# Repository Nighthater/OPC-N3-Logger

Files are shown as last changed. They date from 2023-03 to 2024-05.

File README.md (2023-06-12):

# OPC-N3 Aerosol Sensor Logger

This Logger records the measured data of an OPC-N3 Aerosol sensor every 5 seconds. The measured interval is 2.5sec long.  
It works fully automatic and begins recording when connected with power and needs no further oversight.

## Images

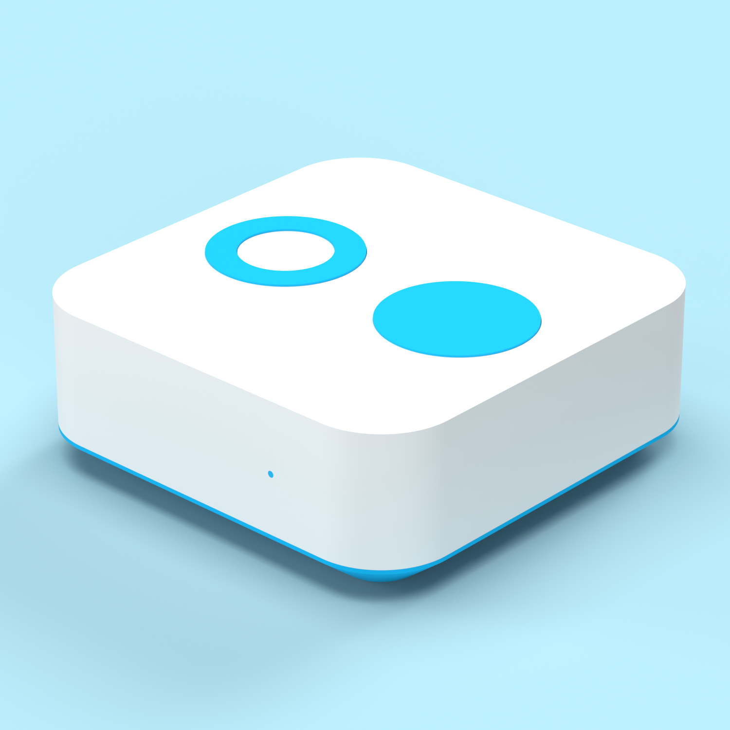
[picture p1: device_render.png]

Render of the Logger  

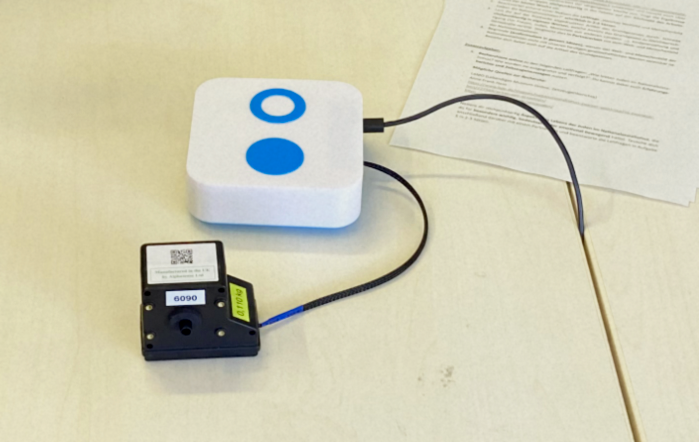
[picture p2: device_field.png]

Logger in the field  
### Size:
  LogBox M (120x120x45mm)  
  5V/300mA  
  
### Specs:
  - NodeMCU V3 LoLin MCU  
  - Real Time Clock DS3231  
  - Micro SD Card Reader  

### IO:
  - Micro USB-B for Power and Serial Data  
  - OPC-N3 Connector Cable  (6pin Molex Pico-Clasp Connector)  
  - OLED Display

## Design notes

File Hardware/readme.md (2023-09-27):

## Part List

### Electrical

- PCB
- Lolin ESP MCU
- SSD1306 OLED Display 0.96"
- MicroSD SPI Board
- DS3231 I²C Board
- Micro USB 30cm Panel Mount Extension with 2x M3 Screws ~29mm hole distance
- 2.54mm THT Screwterminals
- Molex PicoClasp 6pin Cable for the OPC

### Hardware

- 3x M4 Ruthex Threaded Inserts
- 3x Short M4 Screws
- 2x Short M3 Screws (USB Panelmount)
- Hotglue as Strain relief for the OPC Cable

## Additional info

The assembly helpers aid you in soldering the Terminals required to connect the OLED Display and the 6pin OPC Cable to the Mainboard.
You will also need 2 Smaller screws for the Micro USB.
For the Micro SD Card Reader, mount everyting in place without soldering it on.
Solder the Connection to the Mainboard, when the Reader is inserted into the Case, same with the OLED display.

You will have to cut the pico clasp cable, strip the thin cable carefully (I used a Knipex 12 40 200 wire Stripper), and connect it to the terminals.
Use solder on the wire to make it mechanically stronger.
You will need a multimeter to figue out what connection belongs to the cable strand.
I also found it helpful to use braid sleeving to protect the thin cable.

## Schematics

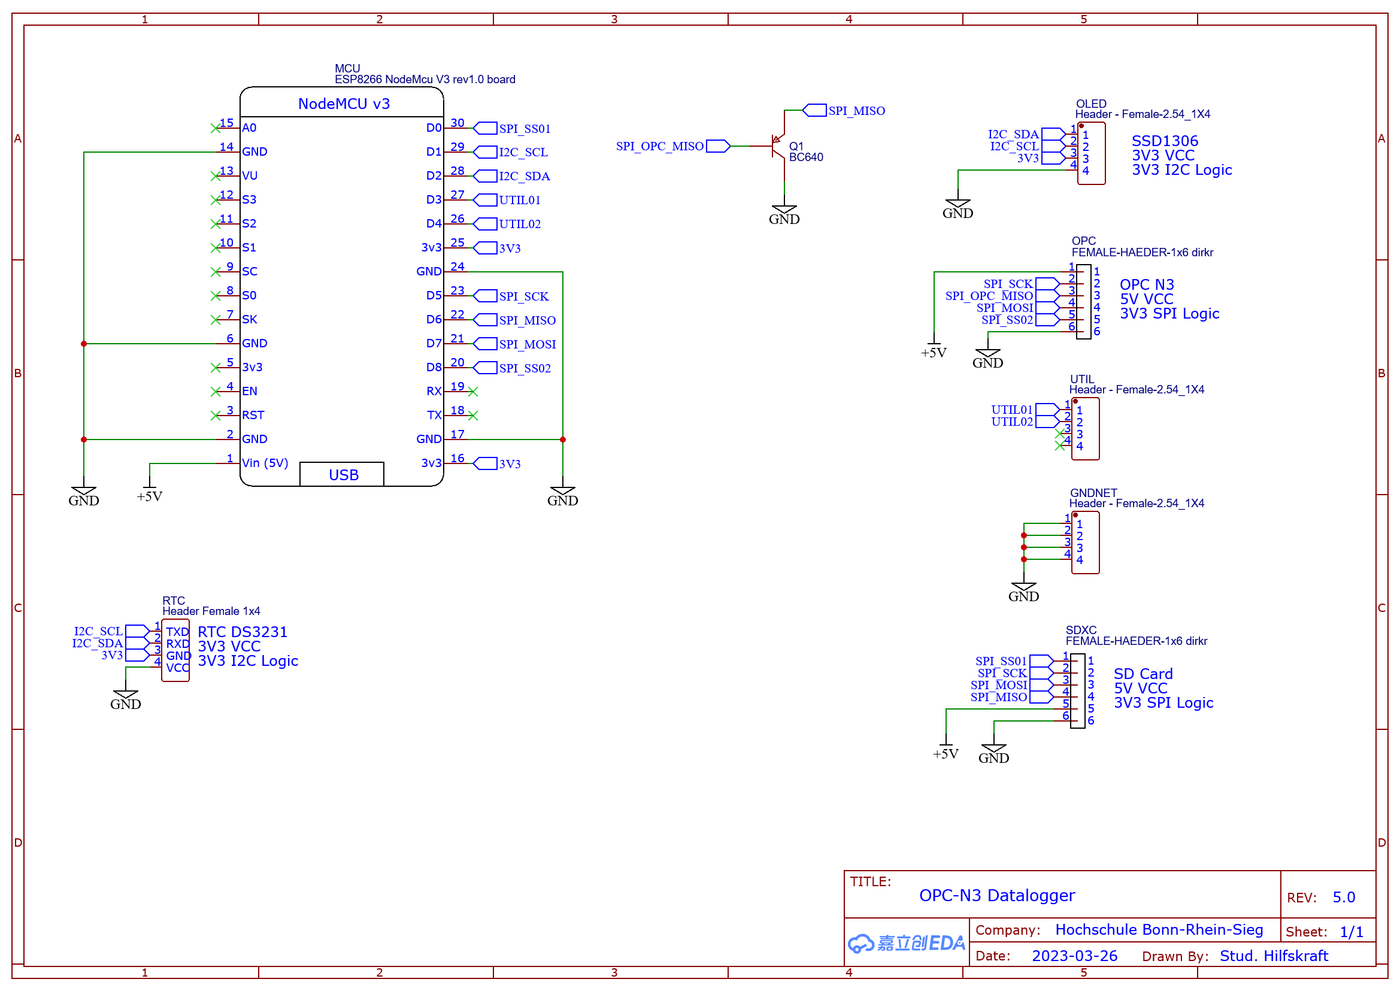
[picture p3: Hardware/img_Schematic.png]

Electrical Schematic  

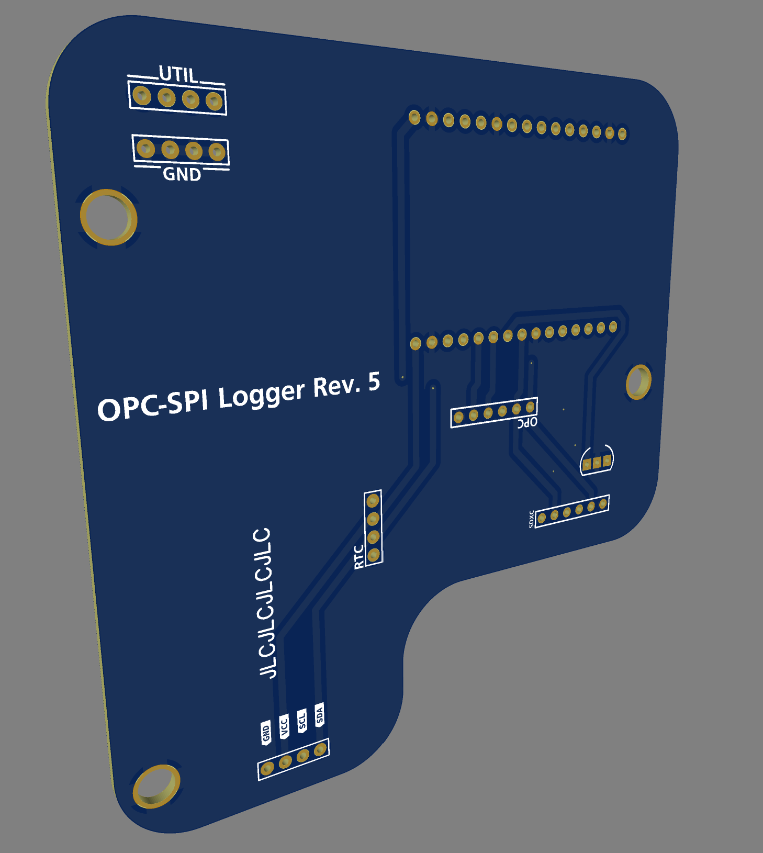
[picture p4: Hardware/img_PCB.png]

Printed Circuit Board screenshot

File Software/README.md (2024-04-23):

The Software comes in two versions.  
One with support for a RTC and one without.

With an RTC, the Filename contains the Date when the File was created.  

Without an RTC the Filename simply increments everytime a File is created, starting always from 0.
If you want to continue from an index, include an empty csv with the Format <DeviceID>_<Index>.csv.

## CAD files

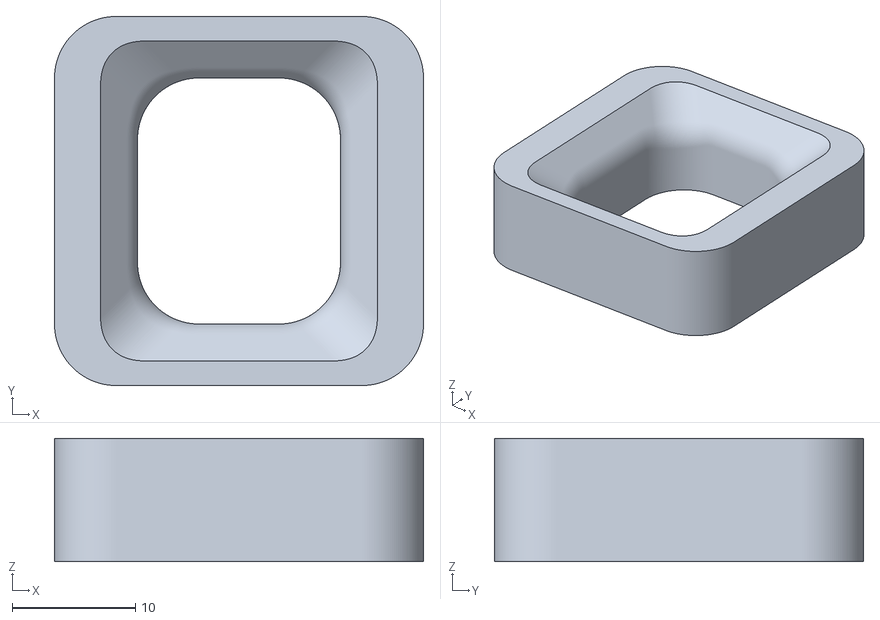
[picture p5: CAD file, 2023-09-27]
Hardware/STL/AssemblyHelper_3xTerminals.stl
30.0 x 30.0 x 10.0

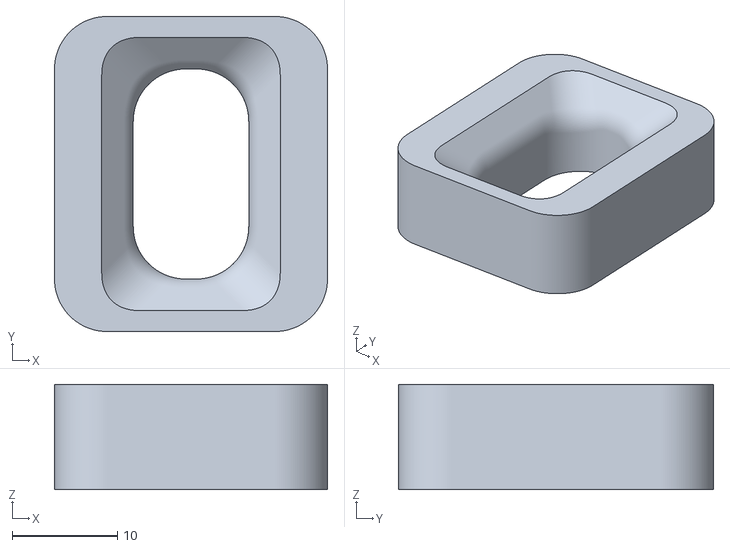
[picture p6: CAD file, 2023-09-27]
Hardware/STL/AssemblyHelper_2xTerminals.stl
26.0 x 30.0 x 10.0

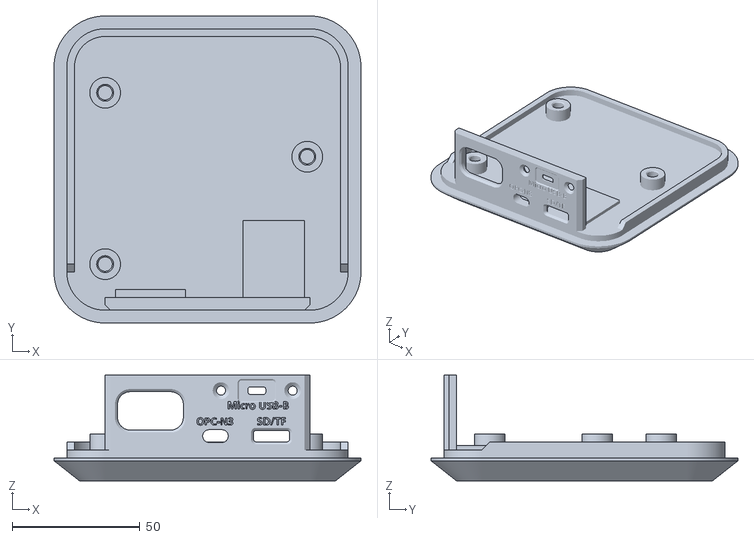
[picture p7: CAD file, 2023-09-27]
Hardware/STL/Casing_Shell_Bottom.stl
120.0 x 120.0 x 41.4

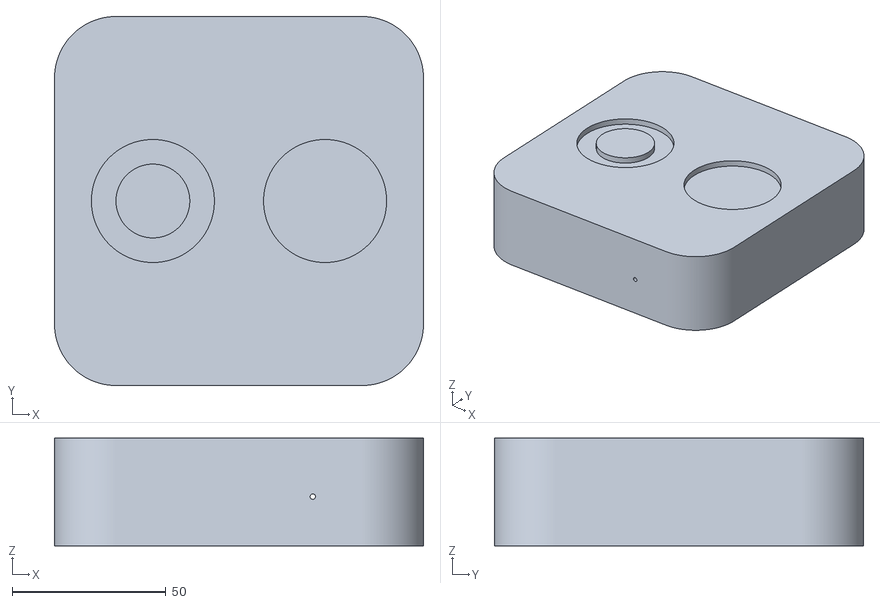
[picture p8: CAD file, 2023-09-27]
Hardware/STL/Casing_Shell_Outer.stl
120.0 x 120.0 x 35.0

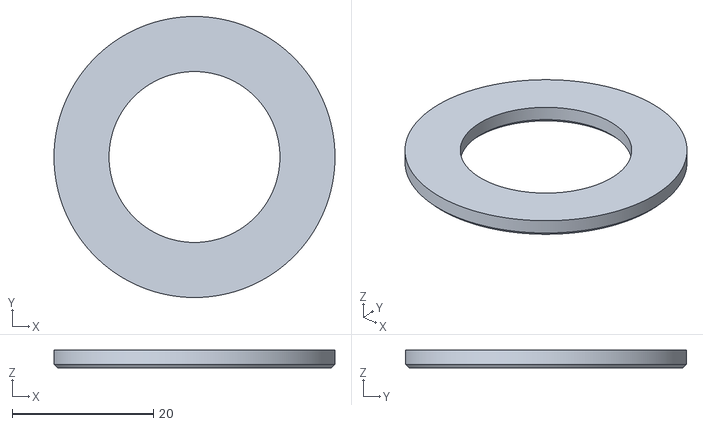
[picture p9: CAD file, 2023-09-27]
Hardware/STL/Casing Logo_Ring.stl
39.8 x 39.8 x 2.50

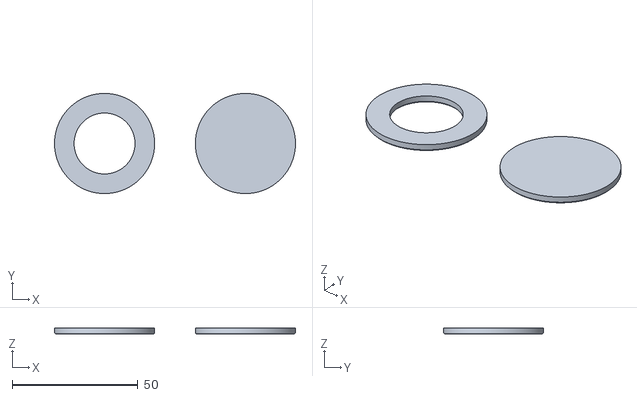
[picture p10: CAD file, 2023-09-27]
Hardware/STL/Casing Logo.stl
95.8 x 39.8 x 2.50

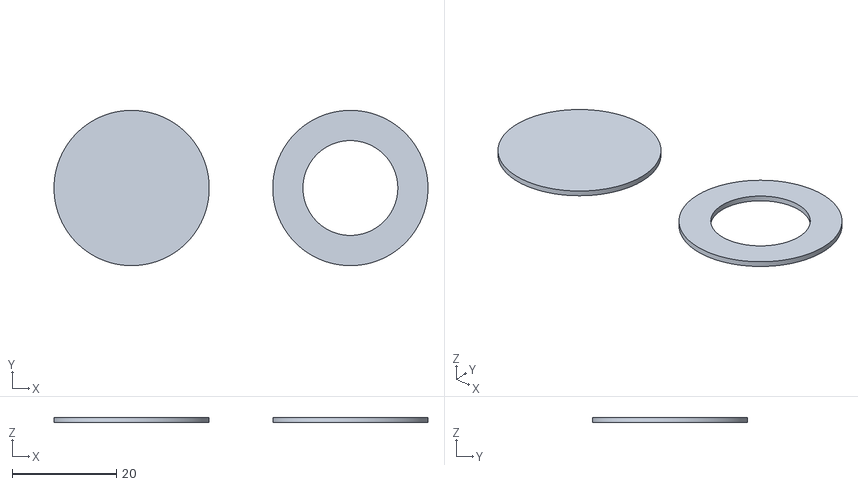
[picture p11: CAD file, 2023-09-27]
Hardware/STL/Casing_Logo_Bottom.stl
71.8 x 29.8 x 1.00

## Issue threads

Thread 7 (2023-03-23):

Screwholes don't fit

Nighthater, 2023-03-23:
The Case is designed for M4 screws, however the PCB has a hole diameter of 3.5mm (M3)

Nighthater, 2023-03-25:
Screwholes have been made fitting in Revision 5

Nighthater, 2023-03-26:
Closed by #11

Closed 2023-03-26.

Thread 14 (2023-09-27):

OPC-N3 Power Requirements

yash-dahima, 2023-09-27:
Hi @Nighthater,

Thanks for this work. I do not have much experience in electronics, so I am facing some trouble in providing proper power to the OPC-N3. Please suggest me how should I power it when using it with along either ESP32 or Raspberry Pi?

Should I power it via RPi/ESP or should I power it separately via 5V mobile charging adapter? I tried to power it via ESP32 Vin and GND pins, but its not working. Your help would be greatly appreciated. Thanks :)

Nighthater, 2023-09-27:
Hi @yash-dahima,

You can power the OPC with either the VIN/GND pins (RPi: 5V/GND) or a 5V Charging adapter. When using an external power supply, like an external charger, make sure that the GND of the Charger and the GND of the ESP/RPi are connected together.

The sensor also won't power on after supplying it with power. You have to send it commands to start up and start measuring data.

Do you currently use an ESP or a RPi to interface with the OPC?
You should also consider that the SPI logic levels on the OPC-N3 Sensor are 3.3V, despite its 5V power supply. I chose an ESP because of that. A RPi uses 5V logic and probably wont recognize a 3.3V high Signal.

yash-dahima, 2023-09-27:
Thanks you very much @Nighthater for your prompt response. I will attempt as per your suggestions and will let you know how it goes.
Again thanks and best wishes :)

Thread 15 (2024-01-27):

RTC sometimes reverts back to 2000-01-01

Nighthater, 2024-01-27:
After setting the time, the RTC will revert to factory settings after a few minutes without power.
Either Hardware or Software fault.

Closed 2024-04-23.

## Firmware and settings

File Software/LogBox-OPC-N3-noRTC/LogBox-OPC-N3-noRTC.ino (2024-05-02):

/*
██╗░░░░░░█████╗░░██████╗░██████╗░░█████╗░██╗░░██╗  ░█████╗░██████╗░░█████╗░░░░░░░███╗░░██╗██████╗░
██║░░░░░██╔══██╗██╔════╝░██╔══██╗██╔══██╗╚██╗██╔╝  ██╔══██╗██╔══██╗██╔══██╗░░░░░░████╗░██║╚════██╗
██║░░░░░██║░░██║██║░░██╗░██████╦╝██║░░██║░╚███╔╝░  ██║░░██║██████╔╝██║░░╚═╝█████╗██╔██╗██║░█████╔╝
██║░░░░░██║░░██║██║░░╚██╗██╔══██╗██║░░██║░██╔██╗░  ██║░░██║██╔═══╝░██║░░██╗╚════╝██║╚████║░╚═══██╗
███████╗╚█████╔╝╚██████╔╝██████╦╝╚█████╔╝██╔╝╚██╗  ╚█████╔╝██║░░░░░╚█████╔╝░░░░░░██║░╚███║██████╔╝
╚══════╝░╚════╝░░╚═════╝░╚═════╝░░╚════╝░╚═╝░░╚═╝  ░╚════╝░╚═╝░░░░░░╚════╝░░░░░░░╚═╝░░╚══╝╚═════╝░


MIT License

Copyright (c) 2024 NIGHTHATER

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
THE SOFTWARE IS PROVIDED "AS IS", WITHOUT WARRANTY OF ANY KIND, EXPRESS OR
IMPLIED, INCLUDING BUT NOT LIMITED TO THE WARRANTIES OF MERCHANTABILITY,
FITNESS FOR A PARTICULAR PURPOSE AND NONINFRINGEMENT. IN NO EVENT SHALL THE
AUTHORS OR COPYRIGHT HOLDERS BE LIABLE FOR ANY CLAIM, DAMAGES OR OTHER
LIABILITY, WHETHER IN AN ACTION OF CONTRACT, TORT OR OTHERWISE, ARISING FROM,
OUT OF OR IN CONNECTION WITH THE SOFTWARE OR THE USE OR OTHER DEALINGS IN THE
SOFTWARE.
*/


//█▄▄ ▄▀█ █▀ █ █▀▀   █░░ █ █▄▄ █▀█ ▄▀█ █▀█ █ █▀▀ █▀
//█▄█ █▀█ ▄█ █ █▄▄   █▄▄ █ █▄█ █▀▄ █▀█ █▀▄ █ ██▄ ▄█


#include "math.h"
#include <Wire.h>
#include <SPI.h>

// OLED DISPLAY SSD1306 | by Adafruit
// https://www.arduino.cc/reference/en/libraries/adafruit-ssd1306/
#include <Adafruit_SSD1306.h>
#include <Adafruit_GFX.h>
#include <splash.h>

// OPC-N3 Aerosol Sensor | by marlon360
// https://github.com/marlon360/opcn3-arduino
#include <OPCN3.h>

// SD Card SPI Reader | by Arduino
// https://www.arduino.cc/reference/en/libraries/sd/
#include <SD.h>


//█▀▄ █▀▀ █▀▀ █░░ ▄▀█ █▀█ ▄▀█ ▀█▀ █ █▀█ █▄░█ █▀
//█▄▀ ██▄ █▄▄ █▄▄ █▀█ █▀▄ █▀█ ░█░ █ █▄█ █░▀█ ▄█

//Pins
//Empty | Reserverd for UTIL Pins

//OLED
#define SCREEN_WIDTH 128 // OLED display width, in pixels
#define SCREEN_HEIGHT 64 // OLED display height, in pixels
#define OLED_RESET    -1 // Reset pin # (or -1 if sharing Arduino reset pin)
#define SCREEN_ADDRESS 0x3C
Adafruit_SSD1306 display(SCREEN_WIDTH, SCREEN_HEIGHT, &Wire, OLED_RESET);

//OPC-N3
OPCN3 myOPCN3(15); // SS PIN in constructor

//SD Card Reader
const int CSpin = 16; //CS PIN SD CARD
File sensorData;


//█░█ ▄▀█ █▀█ █ ▄▀█ █▄▄ █░░ █▀▀ █▀
//▀▄▀ █▀█ █▀▄ █ █▀█ █▄█ █▄▄ ██▄ ▄█

//Measurements
float VAR_Temperature = 0.0;
float VAR_Humidity = 0.0;
float VAR_Humidity_ABS = 0.0;
float VAR_PM_10 = 0.0;
float VAR_PM_2_5 = 0.0;
float VAR_PM_1 = 0.0;

uint16_t VAR_BINS[24];

//File name
String IDevice = "G02"; // Change for Device Name //------------------------------------------------------------------------------------------------------- CUSTOMIZED
String FileName = "";
int FileIndex = 0;

bool FLAG_new_file = false;

//Measurement index count
int VAR_Index = 0;

//Timer and Timing variables
unsigned long TIME_last_SD_save;
unsigned long TIME_last_display_update;
unsigned long TIME_last_RTC_update;
unsigned long TIME_last_OPC_readout;
unsigned long TIME_measurement_start;

//Timer Intervals in ms
int INTERVAL_SD_Save 		= 	5000; 			// Determines the Interval in which measurements are taken / 	in miliseconds 5000ms recommended
int INTERVAL_Display_Update 	= 	200;			// Determines the Interval in which Display is updated / 	in miliseconds 200ms recommended
int INTERVAL_OPC_Readout 	= 	2500;			// Determines the Interval in which OPC is updated / 		in miliseconds 2500ms recommended

//------------------------------------------//
//░██████╗███████╗████████╗██╗░░░██╗██████╗░//
//██╔════╝██╔════╝╚══██╔══╝██║░░░██║██╔══██╗//
//╚█████╗░█████╗░░░░░██║░░░██║░░░██║██████╔╝//
//░╚═══██╗██╔══╝░░░░░██║░░░██║░░░██║██╔═══╝░//
//██████╔╝███████╗░░░██║░░░╚██████╔╝██║░░░░░//
//╚═════╝░╚══════╝░░░╚═╝░░░░╚═════╝░╚═╝░░░░░//
//------------------------------------------//

void setup() {
	// Begin of Script
	// Errorcodes
	// 0x1x SD Card
	// 0x2x Display
	// 0x3x
	// 0x4x
	
	// Begin Serial Comms
	Serial.begin(115200);
	delay(random(50,150));
	
	//initialize OLED Display
	// SSD1306_SWITCHCAPVCC = generate display voltage from 3.3V internally
	if(!display.begin(SSD1306_SWITCHCAPVCC, SCREEN_ADDRESS)) {
		Serial.println(F("FATAL ERROR 0x2B - SSD1306 allocation failed"));
		for(;;); // Don't proceed, loop forever
	}

	display.clearDisplay();
	display.display();

	//Serial
	
	
	//Only the logo
	OLED_ASYNC_display_Startup_Logo();
	delay(random(1000,2000));
	
	//Initialize the Status bar
	OLED_ASYNC_display_Startup_Bar();
	delay(random(1500,2500));
	
	OLED_ASYNC_display_Startup_Bar_Fill(random(2,8));
	delay(random(50,300));

	Serial.print(F("compiled: "));
	Serial.print(__DATE__);
	Serial.println(__TIME__);

	
	OLED_ASYNC_display_Startup_Bar_Fill(random(13,20));
	delay(random(250,750));
	
	//Initialize SD CARD
	pinMode(CSpin, OUTPUT);
	if (!SD.begin(CSpin)) {
		Serial.println(F("FATAL ERROR 0x1A - SD-Card failed, or not present"));
		// don't do anything more:
		for(;;);
	}
	Serial.println(F("SD Card initialized."));

	OLED_ASYNC_display_Startup_Bar_Fill(random(25,35));
	delay(random(250,750));

	//initialize OPC-N3
	// turn on laser, fan and set high gain, use delay to make sure it is setup proper.
	delay(50);
	myOPCN3.initialize();
	delay(500);

	OLED_ASYNC_display_Startup_Bar_Fill(random(45,65));
	delay(random(500,1000));

	
	// Read all filenames
	const char* directory = "/"; // Directory where files are stored
	File dir = SD.open(directory);
	int maxIndex = 0;
	// find the one with the highest File index
	
	while (true) {
    File entry = dir.openNextFile();
		if (!entry) 
		{
			// No more files
			break;
		}
		String filename = entry.name();
		entry.close();

		// Parse the filename to extract the index part
		int underscoreIndex = filename.lastIndexOf('_');
		int dotIndex = filename.lastIndexOf('.');
		
		if (underscoreIndex != -1 && dotIndex != -1) 
		{
		  String indexString = filename.substring(underscoreIndex + 1, dotIndex);
		  int index = indexString.toInt();
		  if (index > maxIndex) 
		  {
			maxIndex = index;
		  }
		}
	}
	dir.close();

	FileIndex = maxIndex + 1;
	
	//Create Filename
	FileName = IDevice + '_' + FileIndex + ".csv";

	sensorData = SD.open(FileName, FILE_WRITE);
	sensorData.close();  //Closing the file

	Serial.println(FileName);

	OLED_ASYNC_display_Startup_Bar_Fill(random(70,80));
	delay(random(1000,1500));

	sensorData = SD.open(FileName, FILE_WRITE);
	if (sensorData) {
		//Write csv header
		sensorData.println("TIME;INDEX;TEMPERATURE;HUM-REL;HUM-ABS;PM10;PM2.5;PM1;BIN0;BIN1;BIN2;BIN3;BIN4;BIN5;BIN6;BIN7;BIN8;BIN9;BIN10;BIN11;BIN12;BIN13;BIN14;BIN15;BIN16;BIN17;BIN18;BIN19;BIN20;BIN21;BIN22;BIN23");
		// close the file:
		sensorData.close();
		Serial.print(F("New File Created: "));
		Serial.println(FileName);
	} else {
		Serial.println(F("FATAL ERROR 0x1B - Cannot write to new File"));
		for(;;);
	}

	OLED_ASYNC_display_Startup_Bar_Fill(100);
	delay(random(1000,1500));

	display.clearDisplay();
	display.display();
	delay(random(150,450));

	//get the measurement since the start
	TIME_measurement_start = millis();

	//set the timing variables to relative zero for the main loop
	TIME_last_SD_save = millis();
	TIME_last_display_update = millis();
	TIME_last_RTC_update = millis();
	TIME_last_OPC_readout = millis();


  SPI.setClockDivider(SPI_CLOCK_DIV32);
	Serial.println(F("Timers set, Setup complete"));

}


//--------------------------------//
//██╗░░░░░░█████╗░░█████╗░██████╗░//
//██║░░░░░██╔══██╗██╔══██╗██╔══██╗//
//██║░░░░░██║░░██║██║░░██║██████╔╝//
//██║░░░░░██║░░██║██║░░██║██╔═══╝░//
//███████╗╚█████╔╝╚█████╔╝██║░░░░░//
//╚══════╝░╚════╝░░╚════╝░╚═╝░░░░░//
//--------------------------------//


void loop() {
	//All Values, Inputs and Outputs will be updated asyncronous

	//Check for Display Update
	if(millis() - TIME_last_display_update > INTERVAL_Display_Update)
	{
		//UPDATE DISPLAY
		TIME_last_display_update = millis() - (millis() - TIME_last_display_update - INTERVAL_Display_Update);

		//Upper Part
		OLED_ASYNC_display_divider();
    OLED_ASYNC_display_Elapsed_Time();
		OLED_ASYNC_display_HBRS_Logo_top_right();

		//Lower Part
		OLED_ASYNC_display_Identifier(IDevice);
		OLED_ASYNC_display_vertical_divider();

		OLED_ASYNC_display_Elapsed_Time();
		OLED_ASYNC_display_HUM_and_TMP(VAR_Temperature,int(VAR_Humidity));
		OLED_ASYNC_display_PM_values(VAR_PM_10,VAR_PM_2_5,VAR_PM_1);
    OLED_ASYNC_display_file_name(FileName);
	}

	//Check for OPC Readout
	if(millis() - TIME_last_OPC_readout > INTERVAL_OPC_Readout)
	{
		//UPDATE OPC
		TIME_last_OPC_readout = millis() - (millis() - TIME_last_OPC_readout - INTERVAL_OPC_Readout);
		OLED_ASYNC_display_OPC_update_icon(15,3);
		
		//OPC readout:
		SPI.setClockDivider(SPI_CLOCK_DIV32);
		SPI.setDataMode(SPI_MODE1);
		HistogramData hist = myOPCN3.readHistogramData();
		
		VAR_Temperature = hist.getTempC();
    VAR_Humidity = hist.getHumidity();
    VAR_Humidity_ABS = CALC_abs_humidity(VAR_Temperature, VAR_Humidity);
		
		VAR_PM_10 = hist.pm10;
		VAR_PM_2_5 = hist.pm2_5;
		VAR_PM_1 = hist.pm1;

    VAR_BINS[0] = hist.binCount0;
    VAR_BINS[1] = hist.binCount1;
    VAR_BINS[2] = hist.binCount2;
    VAR_BINS[3] = hist.binCount3;
    VAR_BINS[4] = hist.binCount4;
    VAR_BINS[5] = hist.binCount5;
    VAR_BINS[6] = hist.binCount6;
    VAR_BINS[7] = hist.binCount7;
    VAR_BINS[8] = hist.binCount8;
    VAR_BINS[9] = hist.binCount9;
    VAR_BINS[10] = hist.binCount10;
    VAR_BINS[11] = hist.binCount11;
    VAR_BINS[12] = hist.binCount12;
    VAR_BINS[13] = hist.binCount13;
    VAR_BINS[14] = hist.binCount14;
    VAR_BINS[15] = hist.binCount15;
    VAR_BINS[16] = hist.binCount16;
    VAR_BINS[17] = hist.binCount17;
    VAR_BINS[18] = hist.binCount18;
    VAR_BINS[19] = hist.binCount19;
    VAR_BINS[20] = hist.binCount20;
    VAR_BINS[21] = hist.binCount21;
    VAR_BINS[22] = hist.binCount22;
    VAR_BINS[23] = hist.binCount23;
		
		delay(100);
		OLED_ASYNC_remove_OPC_update_icon(15,3);

	}

	//Check for SD Card save
	if(millis() - TIME_last_SD_save > INTERVAL_SD_Save)
	{
		SPI.setDataMode(SPI_MODE0);
		//UPDATE SD card
		TIME_last_SD_save = millis() - (millis() - TIME_last_SD_save - INTERVAL_SD_Save);

		OLED_ASYNC_display_save_icon(3,3);
		saveData(sensorData, FileName, VAR_Index, VAR_Temperature, VAR_Humidity, VAR_Humidity_ABS, VAR_PM_10, VAR_PM_2_5, VAR_PM_1, VAR_BINS);
		VAR_Index = VAR_Index + 1;
		
		if( (VAR_Index % 17280 == 0) && (VAR_Index != 0) ) //Since VAR_Index is a int it can only reach up to ~32k until it flips into the negative
		{
			//Schedule creation of new File every 17280 entries (24 h)
			FLAG_new_file = true;
		}
		delay(100);
		OLED_ASYNC_remove_save_icon(3,3);
	}
	
	if(FLAG_new_file == true)
	{
		FLAG_new_file = false;
		
		//Create new File
		//Prepare the Filename
		
		FileIndex = FileIndex + 1;
		
		FileName = IDevice + "_" + FileIndex + ".csv";
		
		sensorData = SD.open(FileName, FILE_WRITE);
		sensorData.close();  //Closing the file

		sensorData = SD.open(FileName, FILE_WRITE);
		if (sensorData) {
			//Write csv header
			sensorData.println("TIME;INDEX;TEMPERATURE;HUM-REL;HUM-ABS;PM10;PM2.5;PM1;BIN0;BIN1;BIN2;BIN3;BIN4;BIN5;BIN6;BIN7;BIN8;BIN9;BIN10;BIN11;BIN12;BIN13;BIN14;BIN15;BIN16;BIN17;BIN18;BIN19;BIN20;BIN21;BIN22;BIN23");
			// close the file:
			sensorData.close();
			Serial.print(F("New File Created: "));
			Serial.println(FileName);
		} else {
			Serial.println(F("FATAL ERROR 0x1B - Cannot write to new File"));
			for(;;);
		}
	}

}



//---------------------------------------------------------------------------------------//
//░██████╗██╗░░░██╗██████╗░██████╗░░█████╗░██╗░░░██╗████████╗██╗███╗░░██╗███████╗░██████╗//
//██╔════╝██║░░░██║██╔══██╗██╔══██╗██╔══██╗██║░░░██║╚══██╔══╝██║████╗░██║██╔════╝██╔════╝//
//╚█████╗░██║░░░██║██████╦╝██████╔╝██║░░██║██║░░░██║░░░██║░░░██║██╔██╗██║█████╗░░╚█████╗░//
//░╚═══██╗██║░░░██║██╔══██╗██╔══██╗██║░░██║██║░░░██║░░░██║░░░██║██║╚████║██╔══╝░░░╚═══██╗//
//██████╔╝╚██████╔╝██████╦╝██║░░██║╚█████╔╝╚██████╔╝░░░██║░░░██║██║░╚███║███████╗██████╔╝//
//╚═════╝░░╚═════╝░╚═════╝░╚═╝░░╚═╝░╚════╝░░╚═════╝░░░░╚═╝░░░╚═╝╚═╝░░╚══╝╚══════╝╚═════╝░//
//---------------------------------------------------------------------------------------//


//█▀ █▀▄   █▀▀ ▄▀█ █▀█ █▀▄   █▀ ▄▀█ █░█ █ █▄░█ █▀▀
//▄█ █▄▀   █▄▄ █▀█ █▀▄ █▄▀   ▄█ █▀█ ▀▄▀ █ █░▀█ █▄█

void saveData(File sensorData, String FileName, int VAR_Index, float VAR_Temperature, float VAR_Humidity, float VAR_Humidity_ABS ,float VAR_PM_10, float VAR_PM_2_5, float VAR_PM_1, uint16_t VAR_BINS[24]){
	if(SD.exists(FileName)) // check the file is still there
	//sensorData.println("DATE;TIME;INDEX;TEMPERATURE;HUM-REL;HUM-ABS;PM10;PM2.5;PM1;BIN0;BIN1;BIN2;BIN3;BIN4;BIN5;BIN6;BIN7;BIN8;BIN9;BIN10;BIN11;BIN12;BIN13;BIN14;BIN15;BIN16;BIN17;BIN18;BIN19;BIN20;BIN21;BIN22;BIN23");
	{ 
		// now append new data file
		sensorData = SD.open(FileName, FILE_WRITE);
		if (sensorData)
		{
			//Write to SD Card
			unsigned long currentMillis = millis();
      unsigned long seconds = currentMillis / 1000;
      unsigned long minutes = seconds / 60;
      unsigned long hours = minutes / 60;
      unsigned long days = hours / 24;
      currentMillis %= 1000;
      seconds %= 60;
      minutes %= 60;
      hours %= 24;
			sensorData.print(hours);
			sensorData.print(':');
			sensorData.print(minutes);
			sensorData.print(':');
			sensorData.print(seconds);
			sensorData.print(';');
			sensorData.print(VAR_Index);
			sensorData.print(';');
			sensorData.print(VAR_Temperature,1); // Maybe replace . with ,
			sensorData.print(';');
			sensorData.print(float(VAR_Humidity),0); // Maybe replace . with ,
			sensorData.print(';');
      sensorData.print(VAR_Humidity_ABS);
      sensorData.print(';');
			sensorData.print(VAR_PM_10,3); // Maybe replace . with ,
			sensorData.print(';');
			sensorData.print(VAR_PM_2_5,3); // Maybe replace . with ,
			sensorData.print(';');
			sensorData.print(VAR_PM_1,3); // Maybe replace . with ,
      for(int i=0;i<=24;i++)
      {
          sensorData.print(';');
          sensorData.print(VAR_BINS[i]);
          
      }
      sensorData.println(';');
			sensorData.close(); // close the file
			
			Serial.print(VAR_Index);
			Serial.print(';');
			Serial.print(hours);
			Serial.print(':');
			Serial.print(minutes);
			Serial.print(':');
			Serial.print(seconds);
			Serial.print(';');
			Serial.print(VAR_Temperature); // Maybe replace . with ,
			Serial.print(';');
			Serial.print(float(VAR_Humidity),0); // Maybe replace . with ,
			Serial.print(';');
      Serial.print(VAR_Humidity_ABS);
      Serial.print(';');
			Serial.print(VAR_PM_10); // Maybe replace . with ,
			Serial.print(';');
			Serial.print(VAR_PM_2_5); // Maybe replace . with ,
			Serial.print(';');
			Serial.print(VAR_PM_1); // Maybe replace . with ,
      for(int i=0;i<=24;i++)
      {
          Serial.print(';');
          Serial.print(VAR_BINS[i]);
          
      }
      Serial.println(';');
		}
	}
	else{
		Serial.println("0x1A - Error writing to file !");
		//TODO ADD ALERT
	}
}


//█▀ ▀█▀ ▄▀█ █▀█ ▀█▀ █░█ █▀█
//▄█ ░█░ █▀█ █▀▄ ░█░ █▄█ █▀▀

void OLED_ASYNC_display_Startup_Logo()
{
	display.clearDisplay();
	display.fillCircle(47, 28, 11, WHITE);
	display.fillCircle(47, 28, 6, BLACK);
	display.fillCircle(80, 28, 11, WHITE);
	display.display();
}

void OLED_ASYNC_display_Startup_Bar()
{
	display.fillRect(19,48,90,5,WHITE);
	display.fillRect(18,49,92,3,WHITE);
	display.fillRect(19,49,90,3,BLACK);
	display.display();
}

void OLED_ASYNC_display_Startup_Bar_Fill(int percentage)
{
	display.drawFastHLine(20,50,int(float(percentage)/100.0*88.0),WHITE);
	display.display();
}

//█▀█ █░░ █▀▀ █▀▄   █░█ █
//█▄█ █▄▄ ██▄ █▄▀   █▄█ █

void OLED_ASYNC_display_divider()
//shows a horizontal line dividing the display
//0,0 is at top right
{
	display.drawFastHLine(0,15,128,WHITE);
	display.display();
}

void OLED_ASYNC_display_vertical_divider()
{
	display.drawFastVLine(71,19,31,WHITE);
	display.display();
}

void OLED_ASYNC_display_save_icon(int x, int y)
// displays a save icon at x,y where the coords are the top right corner
{
	display.drawFastHLine(x,y+7,8,WHITE); // Bottom Outine
	display.drawFastHLine(x+1,y+1,6,WHITE); // Top Outline
	display.drawFastVLine(x,y+2,5,WHITE); // Left Outline
	display.drawFastVLine(x+7,y+2,5,WHITE); // Right Outline

	display.drawFastVLine(x+2,y+4,3,WHITE); // Left Faceline
	display.drawFastVLine(x+5,y+4,3,WHITE); // Right Faceline
	display.drawFastHLine(x+2,y+4,3,WHITE); // Top Faceline

	display.drawPixel(x+2,y+1,WHITE);
	display.drawPixel(x+3,y+2,WHITE);
	display.drawPixel(x+4,y+2,WHITE);
	display.drawPixel(x+5,y+1,WHITE); //Metal Tray Pixels
	display.display();
}

void OLED_ASYNC_remove_save_icon(int x, int y)
{
	display.fillRect(x,y,8,8,BLACK);
	display.display();
}

void OLED_ASYNC_display_HBRS_Logo_top_right()
// Draws the HBRS logo in the top Right
{
	display.fillCircle(105, 7, 4, WHITE);
	display.fillCircle(105, 7, 2, BLACK);
	display.fillCircle(118, 7, 4, WHITE);
	display.display();
}

void OLED_ASYNC_display_OPC_update_icon(int x, int y)
{
	display.drawFastVLine(x  ,y+6,2,WHITE);
	display.drawFastVLine(x+2,y+4,4,WHITE);
	display.drawFastVLine(x+4,y+2,6,WHITE);
	display.drawFastVLine(x+6,y  ,8,WHITE);
	display.display();
}

void OLED_ASYNC_remove_OPC_update_icon(int x, int y)
{
	display.fillRect(x,y,7,8,BLACK);
	display.display();
}

void OLED_ASYNC_display_Elapsed_Time()
{
	unsigned long currentMillis = millis();
	unsigned long seconds = currentMillis / 1000;
	unsigned long minutes = seconds / 60;
	unsigned long hours = minutes / 60;
	unsigned long days = hours / 24;
	currentMillis %= 1000;
	seconds %= 60;
	minutes %= 60;
	hours %= 24;

	//Fill the previously written pixels with Black
	display.fillRect(80,41,48,7,BLACK);

	display.setCursor(80,41);
	//if minutes<10 then print a 0?

	display.print("E ");
	display.print(hours);
	display.print("h ");
	display.print(minutes);
	display.print("m");
	display.display();
}

void OLED_ASYNC_display_Identifier(String IDevice)
{
	display.fillRect(20,54,104,7,BLACK);
	display.setCursor(20,54);
	display.print("OPC-N3-HBRS-");
  display.print(IDevice);

	display.display();
}

void OLED_ASYNC_display_HUM_and_TMP(float temperature, int humidity)
{
	display.fillRect(80,21,48,7,BLACK);
	display.fillRect(80,31,48,7,BLACK);
	display.setCursor(80,21);
	display.print("T ");
	display.print(temperature, 1);
	display.print(" C");

	display.setCursor(80,31);
	display.print("H ");
	display.print(humidity);
	display.print("%");

	display.display();
}

void OLED_ASYNC_display_PM_values(float PM_10 ,float PM_2_5, float PM_1)
{
	display.fillRect(8,21,62,7,BLACK);
	display.fillRect(8,31,62,7,BLACK);
	display.fillRect(8,41,48,7,BLACK);

  display.setTextColor(WHITE);
	display.setCursor(8,21);
	display.print(PM_10,1);
	display.print("p");

	display.setCursor(8,31);
	display.print(PM_2_5,1);
	display.print("p");

	display.setCursor(8,41);
	display.print(PM_1,1);
	display.print("p");

	display.display();
}

void OLED_ASYNC_display_file_name(String FileName)
{
  display.fillRect(41,4,49,10,BLACK); // black out current filename
  display.setCursor(41,4);
  display.print(FileName);
  display.display();
}

// Calculations

float CALC_abs_humidity(float t, float hyd)
{
  float abs_humidity;
  abs_humidity = (6.112*pow(2.71828182,((17.67*float(t))/(float(t)+243.5)))*float(hyd)*18.02 )/((273.15+float(t))*100*0.08314);
  return abs_humidity;
}

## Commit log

2023-03-19 Added Hardware
    PCB, Gerber Files, Renders
2023-03-23 Add SPI_Mode selecting
    Fixes issue where SD-Card interferes with the OPC
    [LogBox-OPC-N3.ino]
2023-03-26 PCB Revision 05
2023-09-27 Update LogBox-OPC-N3.ino
    Changed ug/m3 to counts per second in the Oled display
    Resolves #13
    [LogBox-OPC-N3.ino]
2023-09-27 Added Stl Files for 3D Printing
    [AssemblyHelper_2xTerminals.stl, AssemblyHelper_3xTerminals.stl, Casing Logo.stl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]
2024-02-06 Switched Locations
2024-05-02 Added current File Name to display
